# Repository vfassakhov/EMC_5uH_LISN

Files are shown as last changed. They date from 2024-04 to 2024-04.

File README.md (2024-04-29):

# 5µH LISN(Line Impedance Stabilization Network)

Open Source Hardware Dual 5µH DC LISN with 10dB Attenuator and Transient Limiter for Spectrum Analyzer EMC work.

A LISN is a [Line Impedance Stabilization Network](https://en.wikipedia.org/wiki/Line_Impedance_Stabilization_Network) used in conducted emissions testing.

The AIM of this Dual LISN is to be used for EMC pre-testing with frequency range 30kHz(or lower) to 110MHz(or up to 150MHz or more).

Fork from the [original project](https://github.com/bvernoux/EMC_5uH_LISN), the main changes are made the following:

* Convert project to [KiCad 8.0](https://www.kicad.org) version
* Added [KiBot](https://github.com/INTI-CMNB/KiBot) configuration, for automated generation of the documentation
* Improvement in this design: 
  * Replace Keystone 575-8 by screwed type Chinese alternative
  * Inductors are replaced by more affordable (need to make some tests)
  * BOM changes for cheaper Chinese alternatives
  * Another case (Gainta) is chosen

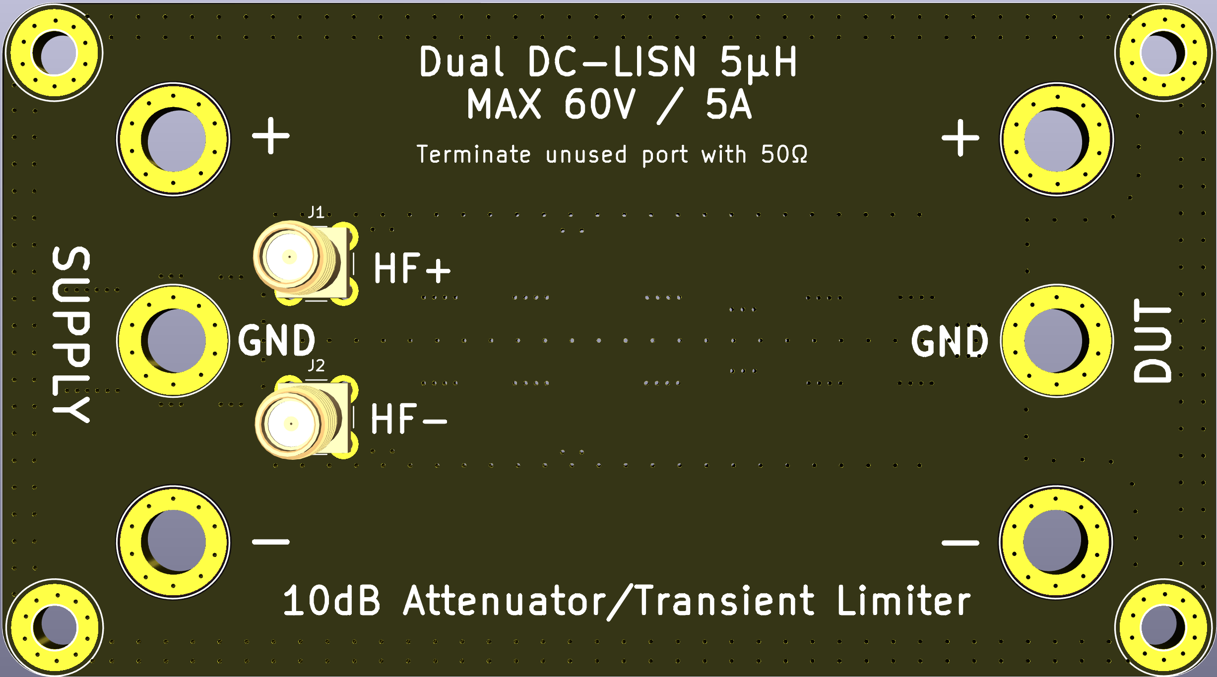
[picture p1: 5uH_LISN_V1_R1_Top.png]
picture of 5uH_LISN_V1_R0_Top

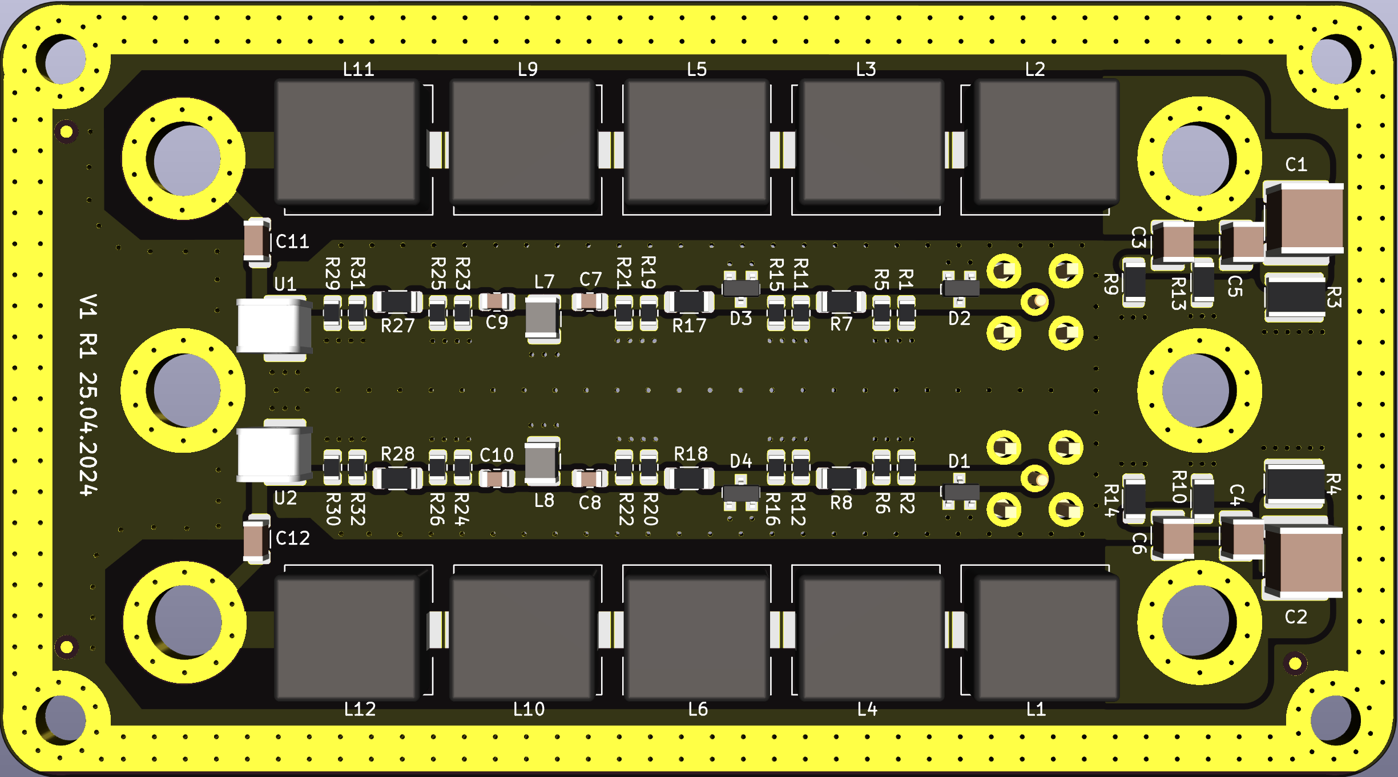
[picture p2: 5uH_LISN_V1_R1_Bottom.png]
picture of 5uH_LISN_V1_R0_Bottom


This work is heavily based on work from others mainly **Jay_Diddy_B** & **Noy** from EEVBLOG forum.

See all links related to the original Dual 5µH LISN:
* https://www.eevblog.com/forum/projects/5uh-lisn-for-spectrum-analyzer-emcemi-work/75/
* https://www.eevblog.com/forum/projects/5uh-lisn-for-spectrum-analyzer-emcemi-work/msg3420102/#msg3420102

Video related to EMC Conducted Emissions / LISN:
* Rohde Schwarz video Understanding LISNs: 
  * This video explains the design and function of a LISN (line impedance stabilization network) and how LISNs are used in conducted EMC testing.
  * https://www.youtube.com/watch?v=QPJzp66Yvzs
* EMC Conducted Emissions: How to connect and set up a LISN:
  * In this video Dr. Ali Shirsavar shows how you can connect and set up a LISN ready for pre-compliance testing of EMC conducted emissions.
  * https://www.youtube.com/watch?v=28oDdL9RnWM

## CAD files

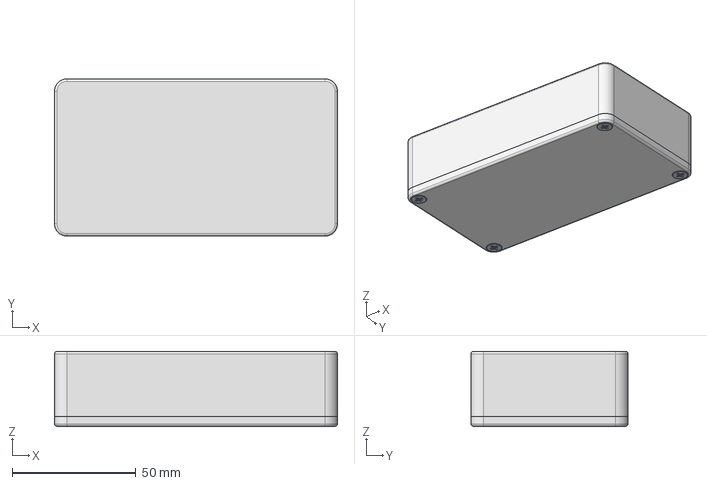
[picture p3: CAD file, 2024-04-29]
3d_step/Gainta_B013_assy.stp
114.5 x 63.6 x 30.4 mm

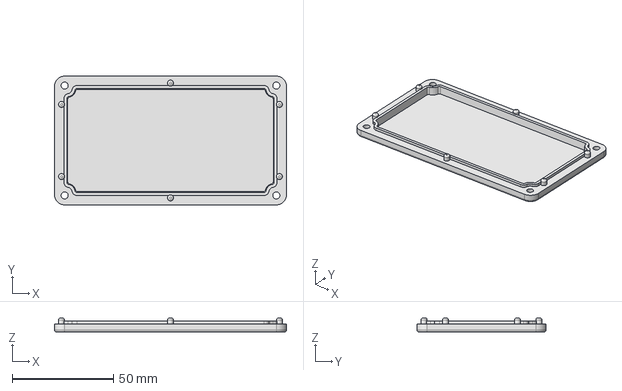
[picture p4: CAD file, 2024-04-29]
3d_step/Gainta_B013_bottom.stp
114.5 x 63.6 x 7.00 mm

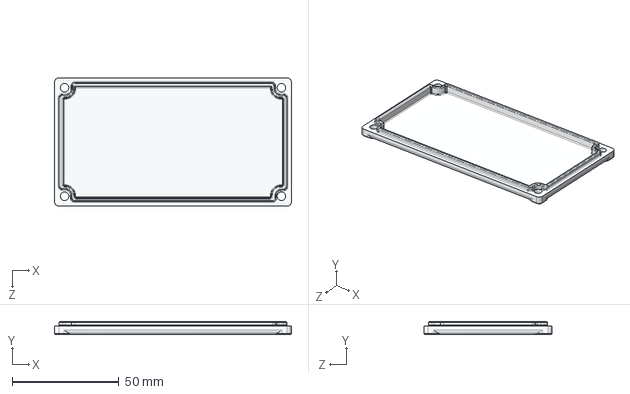
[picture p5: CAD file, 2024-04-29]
3d_step/G0124_BOT.STEP
111.0 x 6.00 x 60.0 mm

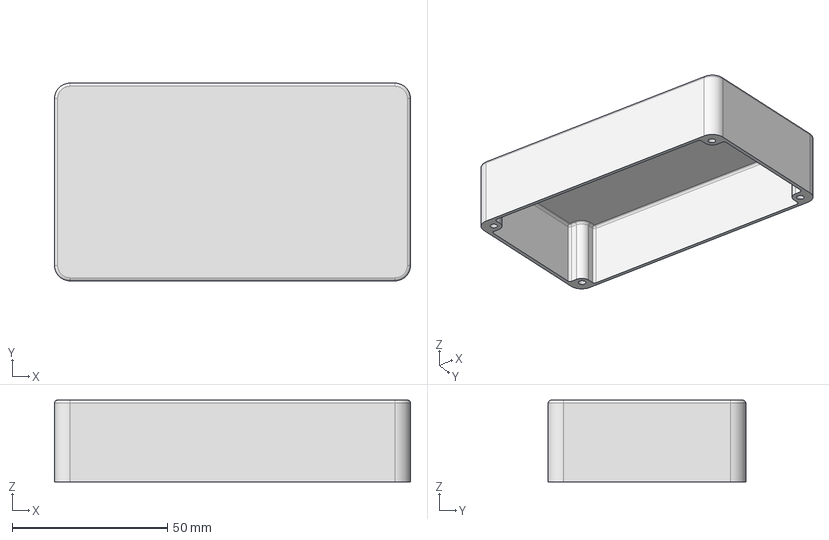
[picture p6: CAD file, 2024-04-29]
3d_step/Gainta_B013_top.stp
114.5 x 63.6 x 26.3 mm

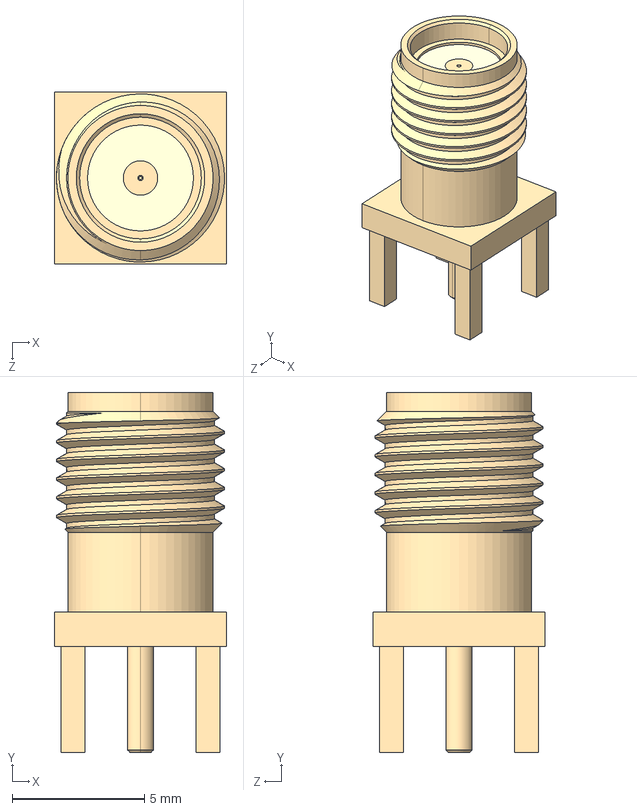
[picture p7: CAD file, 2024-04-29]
3d_step/SMA CONNECTOR--3DModel-STEP-1.STEP
6.50 x 13.6 x 6.50 mm

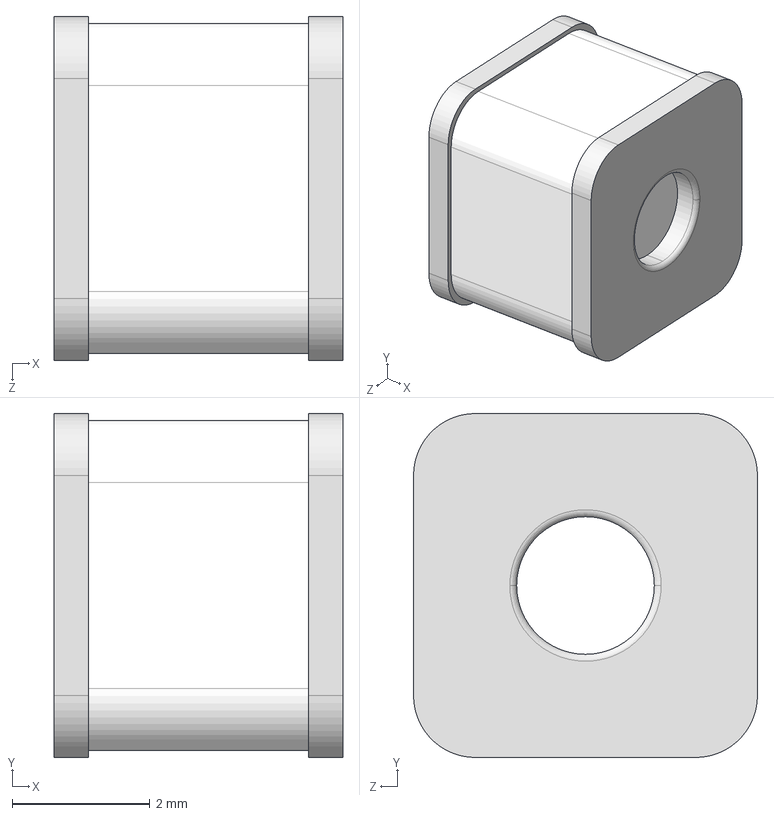
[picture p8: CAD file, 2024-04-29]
3d_step/User Library-SH_Series.STEP
4.20 x 5.00 x 5.00 mm

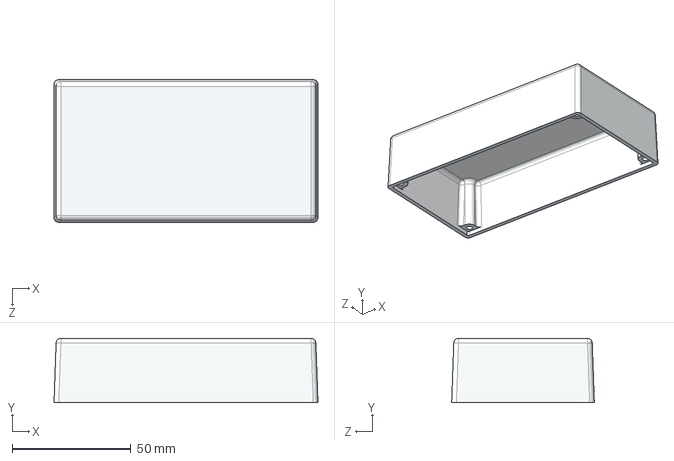
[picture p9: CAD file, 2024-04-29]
3d_step/G0124_TOP.STEP
111.0 x 27.0 x 60.0 mm

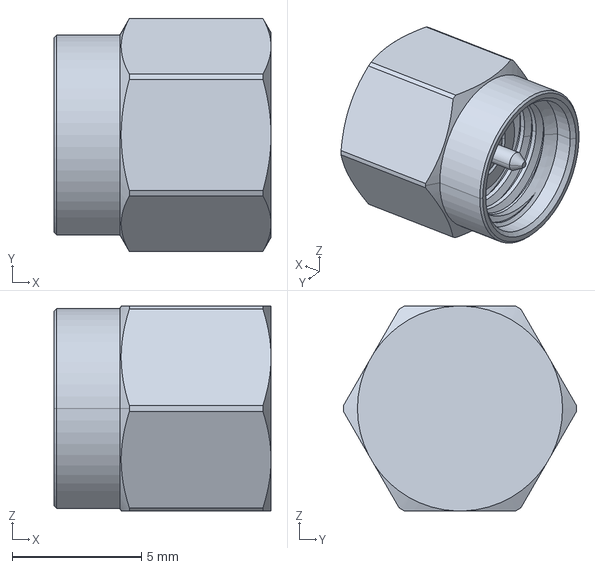
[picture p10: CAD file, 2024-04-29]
3d_step/132360.stp
8.38 x 9.00 x 7.91 mm

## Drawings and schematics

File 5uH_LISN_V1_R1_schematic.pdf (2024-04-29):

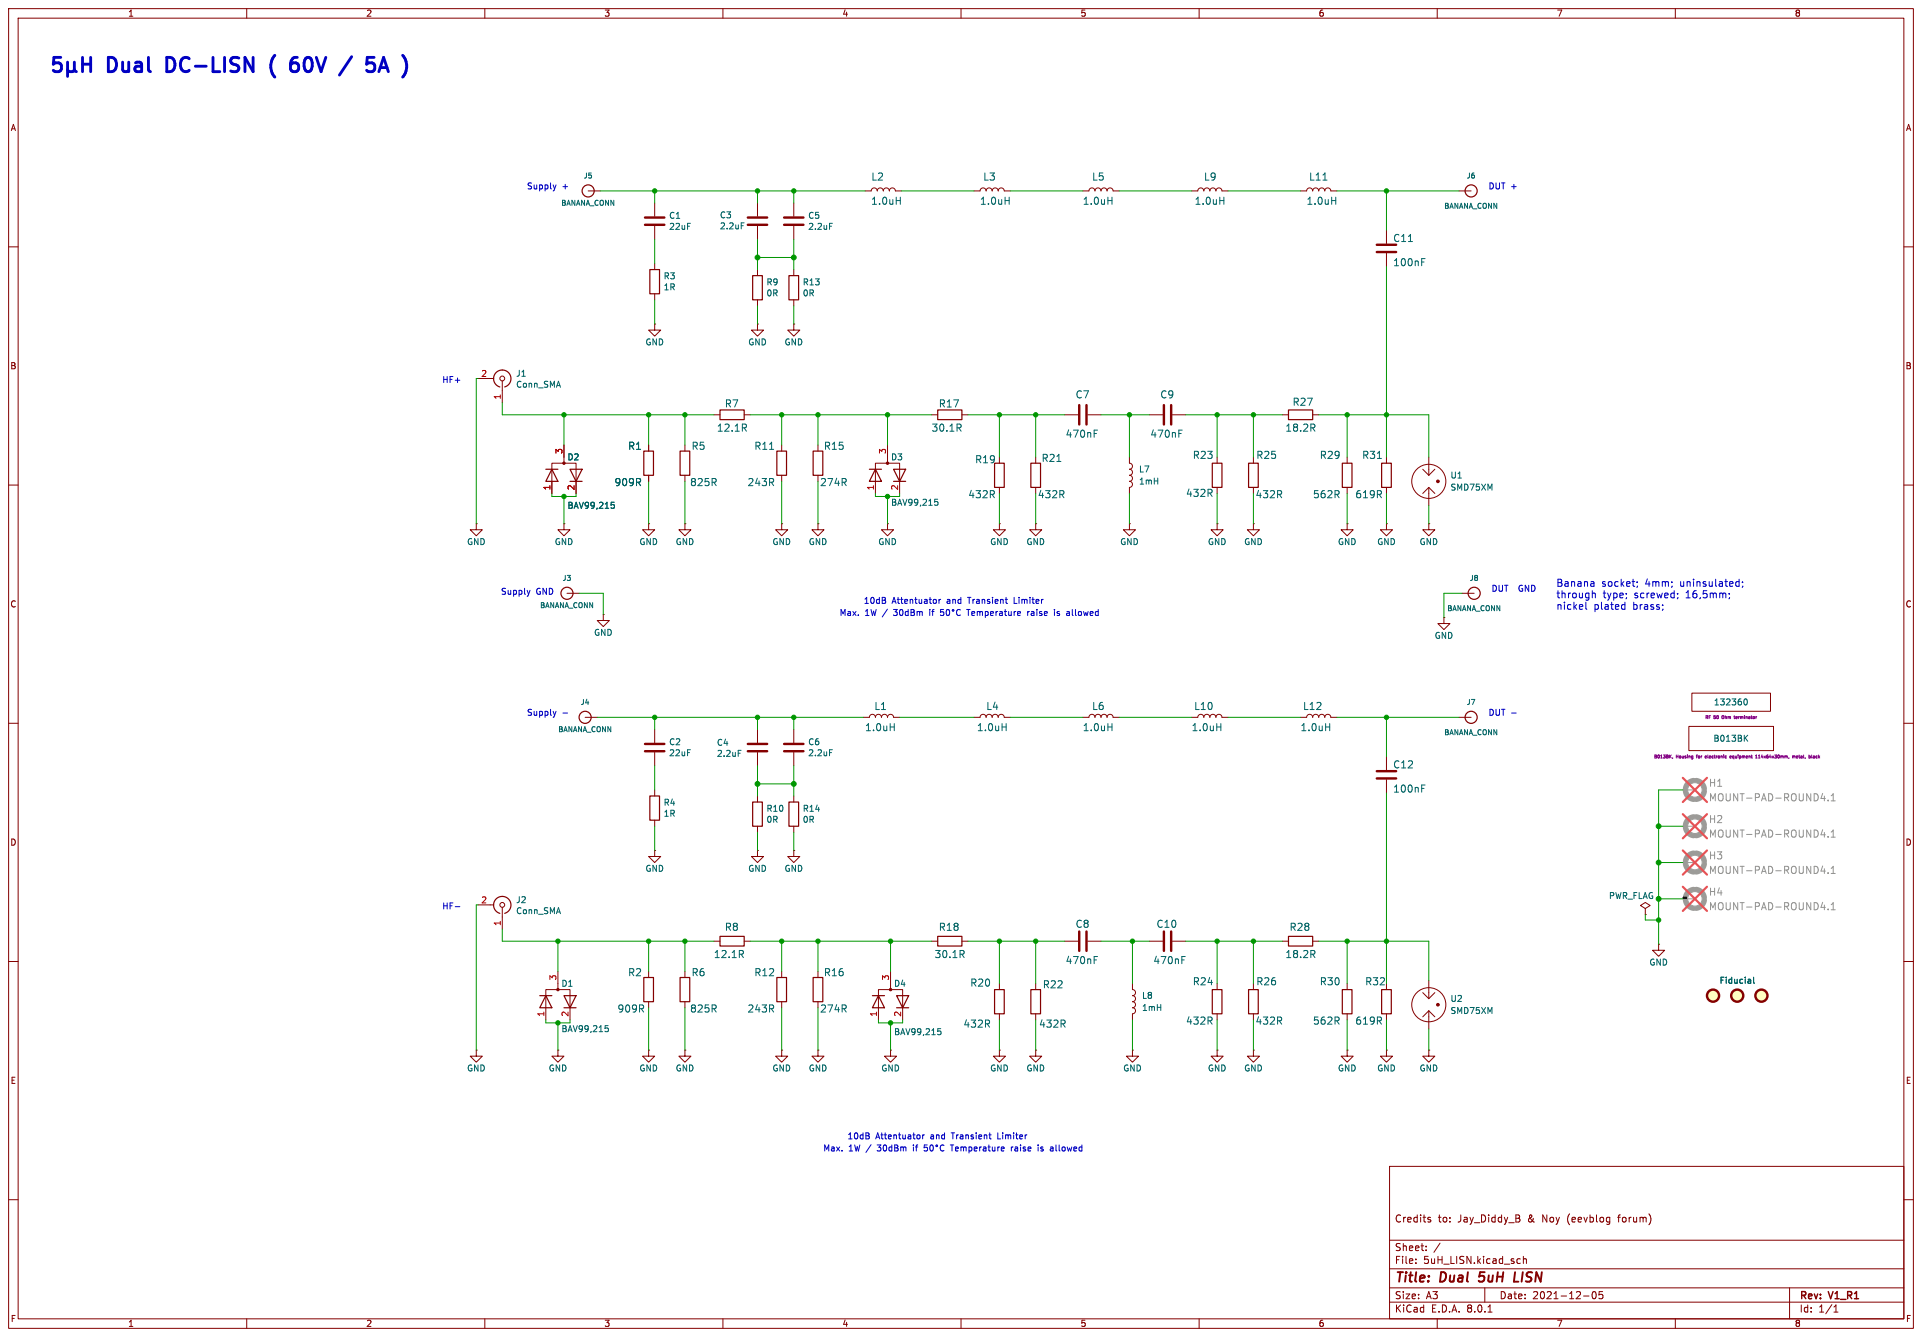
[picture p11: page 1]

RF 50 Ohm terminator H4 MOUNT-PAD-ROUND4.1 H2 MOUNT-PAD-ROUND4.1 H1 MOUNT-PAD-ROUND4.1 H3 MOUNT-PAD-ROUND4.1 B013BK

Id: 1/1 Title: Dual 5uH LISN

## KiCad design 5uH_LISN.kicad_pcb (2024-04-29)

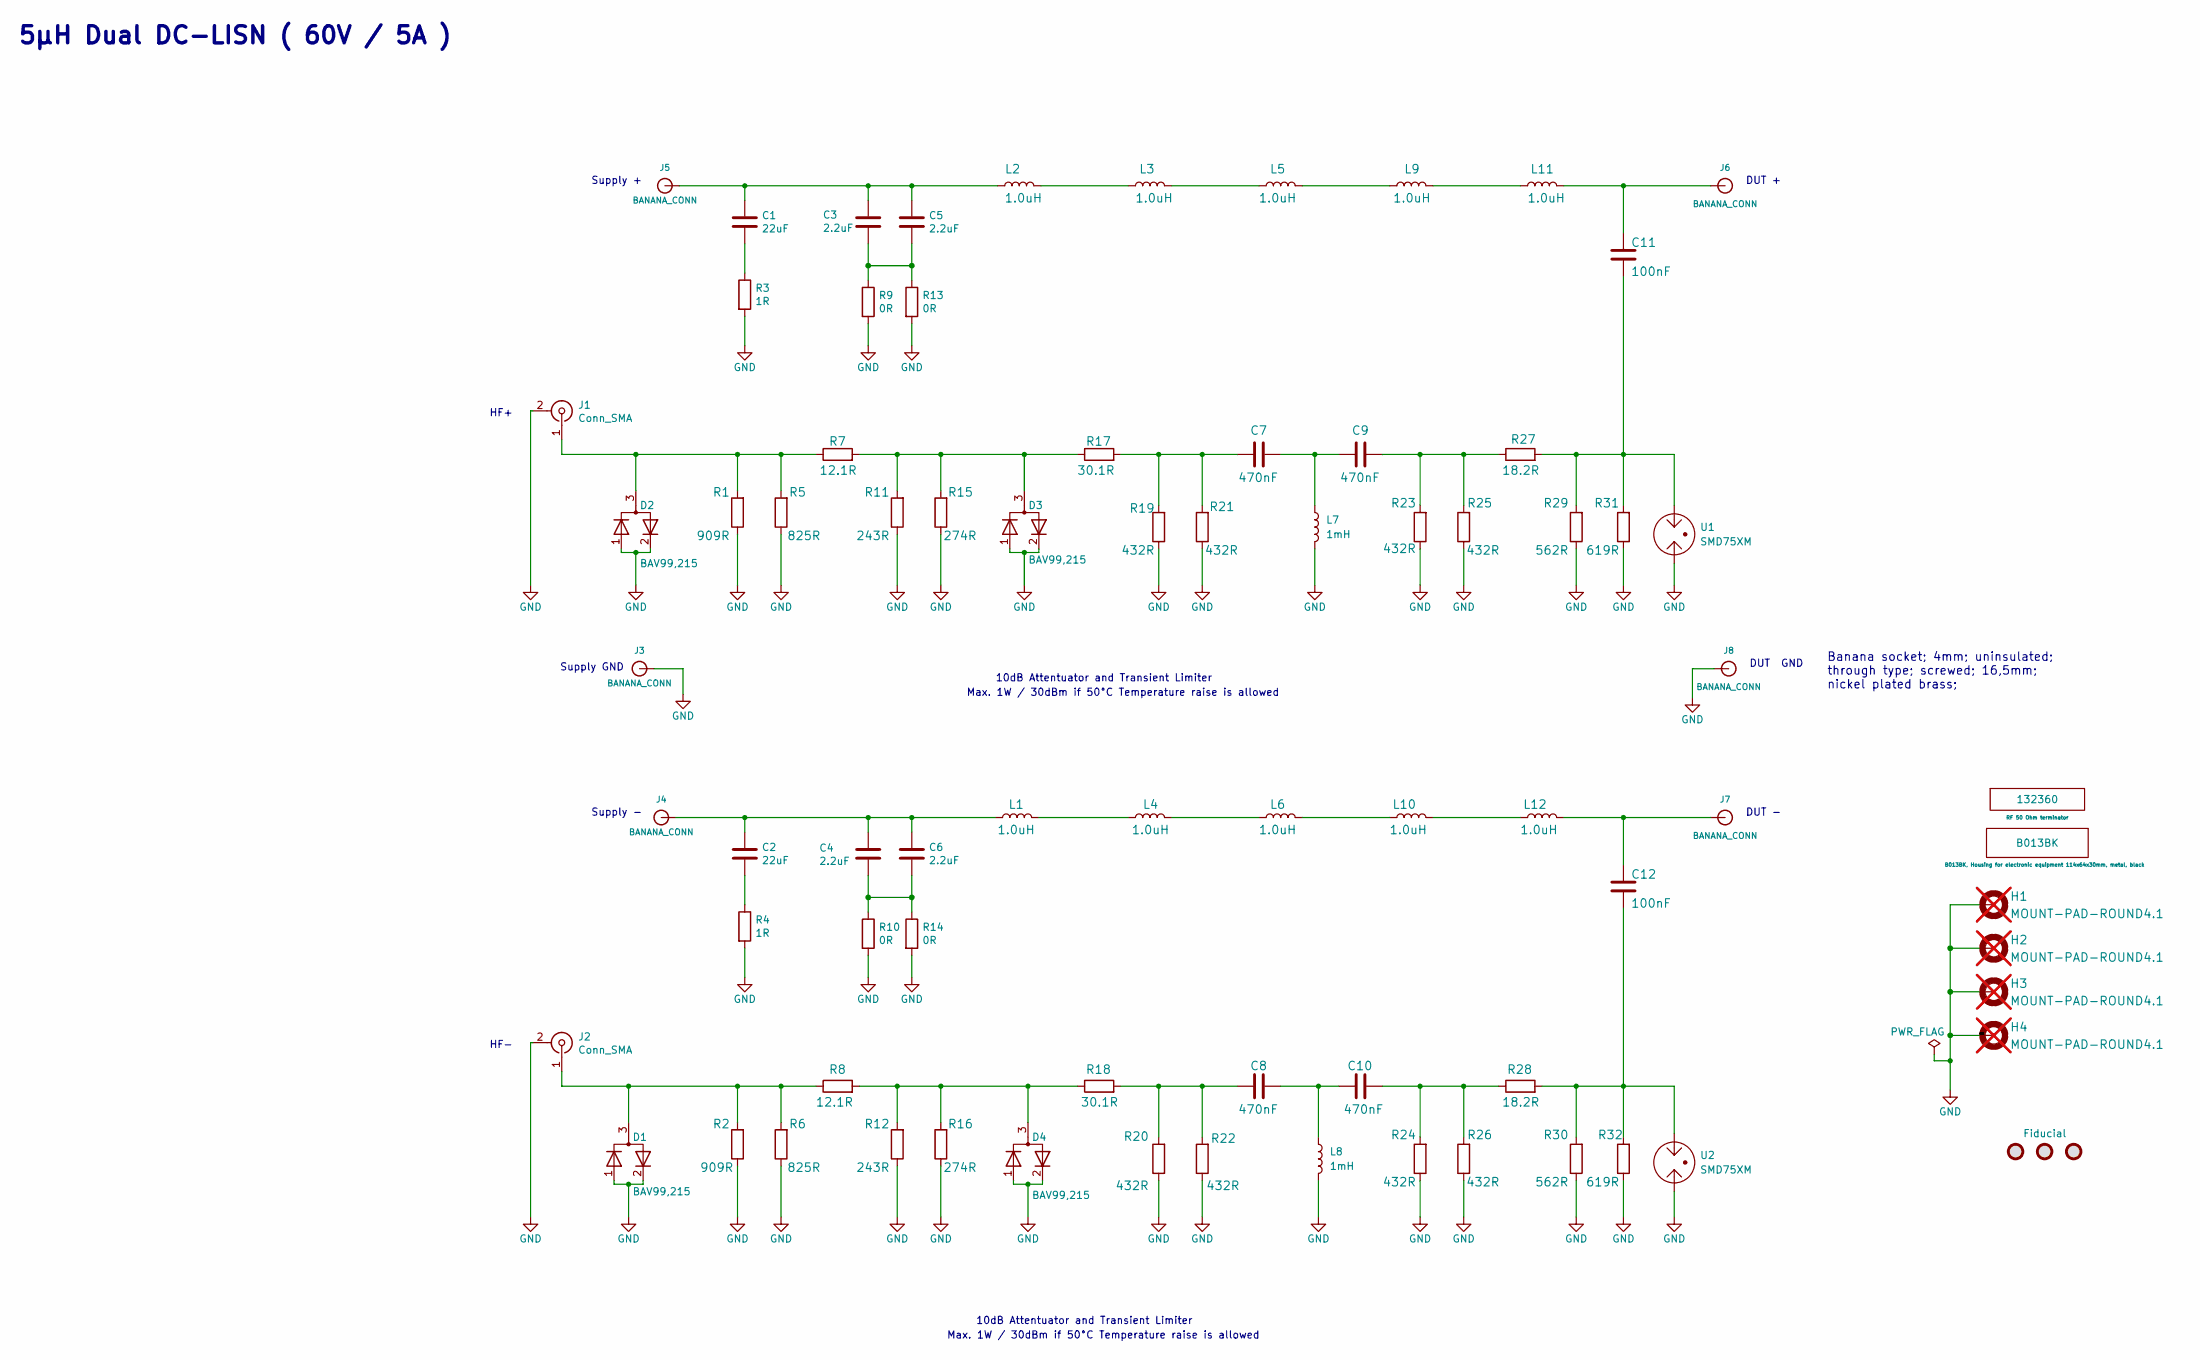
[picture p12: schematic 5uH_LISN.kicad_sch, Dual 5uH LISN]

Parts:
C1, C2: 22uF; C_2220_5650Metric; Part number KRM55WR72A226MH01L
C3, C4, C5, C6: 2.2uF; C_1210_3225Metric; Part number CC1210KKX7R0BB225
C7, C8, C9, C10: 470nF; C_0805_2012Metric; Part number CC0805KKX7R0BB474
C11, C12: 100nF; C_1206_3216Metric; Part number CC1206KKX7RYBB104
CASE1: B013BK; Part number B013BK
D1, D2, D3, D4: BAV99,215; SOT23-DIODEDUAL; Part number BAV99,215
FID1, FID2, FID3: Fiducial; Fiducial_1mm_Mask2mm
H1, H2, H3, H4: MOUNT-PAD-ROUND4.1; 4,1-PAD; not fitted
J1, J2: Conn_SMA; SMB_Jack_Vertical; Part number KLS1-SMA001
J3, J4, J5, J6, J7, J8: BANANA_CONN; 6,1-PAD; Part number 28.230
L1, L2, L3, L4, L5, L6, L9, L10, L11, L12: 1.0uH; SMS1040; Part number SMS1040-1R0MT
L7, L8: 1mH; L_1210_3225Metric; Part number NLFV32T-102K-EF
R1, R2: 909R; R_0805_2012Metric; Part number PTFR0805B909RP9
R3, R4: 1R; R_1218_3246Metric; Part number RC1218FK-071RL
R5, R6: 825R; R_0805_2012Metric; Part number RT0805BRD07825RL
R7, R8: 12.1R; R_1206_3216Metric; Part number RT1206BRD0712R1L
R9, R10, R13, R14: 0R; R_1206_3216Metric; Part number RC1206JR-7W0RL
R11, R12: 243R; R_0805_2012Metric; Part number RT0805BRD07243RL
R15, R16: 274R; R_0805_2012Metric; Part number RT0805BRD07274RL
R17, R18: 30.1R; R_1206_3216Metric; Part number AR06DTDV30R1
R19, R20, R21, R22, R23, R24, R25, R26: 432R; R_0805_2012Metric; Part number RT0805BRD07432RL
R27, R28: 18.2R; R_1206_3216Metric; Part number RT1206BRD0718R2L
R29, R30: 562R; R_0805_2012Metric; Part number RT0805BRD07562RL
R31, R32: 619R; R_0805_2012Metric; Part number RT0805BRE07619RL
RF1: 132360; RF_CAP; Part number 132360
U1, U2: SMD75XM; Fuse_1812_4532Metric; Part number SMD75XM

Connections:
GND: D1.1 (K), D1.2 (K), D2.1 (K), D2.2 (K), D3.1 (K), D3.2 (K), D4.1 (K), D4.2 (K), H1.B4,1 (MOUNT), H2.B4,1 (MOUNT), H3.B4,1 (MOUNT), H4.B4,1 (MOUNT), J1.2 (Ext), J2.2 (Ext), J3.1, J8.1, L7.2, L8.2, R1.1, R2.1, R3.2, R4.2, R5.1, R6.1, R9.2, R10.2, R11.1, R12.1, R13.2, R14.2, R15.1, R16.1, R19.1, R20.1, R21.1, R22.1, R23.1, R24.1, R25.1, R26.1, R29.1, R30.1, R31.1, R32.1, U1.1, U2.1
unnamed: C1.2, R3.1
unnamed: C2.2, R4.1
unnamed: C3.2, C5.2, R9.1, R13.1
unnamed: C4.2, C6.2, R10.1, R14.1
unnamed: C7.1, R17.2, R19.2, R21.2
unnamed: C7.2, C9.1, L7.1
unnamed: C8.1, R18.2, R20.2, R22.2
unnamed: C9.2, R23.2, R25.2, R27.1
unnamed: C8.2, C10.1, L8.1
unnamed: C10.2, R24.2, R26.2, R28.1
unnamed: C11.2, R27.2, R29.2, R31.2, U1.2
unnamed: C12.2, R28.2, R30.2, R32.2, U2.2
unnamed: D1.3 (A), J2.1 (In), R2.2, R6.2, R8.1
unnamed: D2.3 (A), J1.1 (In), R1.2, R5.2, R7.1
unnamed: D3.3 (A), R7.2, R11.2, R15.2, R17.1
unnamed: D4.3 (A), R8.2, R12.2, R16.2, R18.1
unnamed: C2.1, C4.1, C6.1, J4.1, L1.1
unnamed: C1.1, C3.1, C5.1, J5.1, L2.1
unnamed: C11.1, J6.1, L11.2
unnamed: C12.1, J7.1, L12.2
unnamed: L1.2, L4.1
unnamed: L2.2, L3.1
unnamed: L3.2, L5.1
unnamed: L4.2, L6.1
unnamed: L5.2, L9.1
unnamed: L6.2, L10.1
unnamed: L10.2, L12.1
unnamed: L9.2, L11.1

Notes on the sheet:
10dB Attentuator and Transient Limiter
Supply -
Max. 1W / 30dBm if 50°C Temperature raise is allowed
5µH Dual DC-LISN ( 60V / 5A )
DUT +
Supply +
DUT GND
Banana socket; 4mm; uninsulated; through type; screwed; 16,5mm; nickel plated brass;
Supply GND
HF-
HF+
DUT -

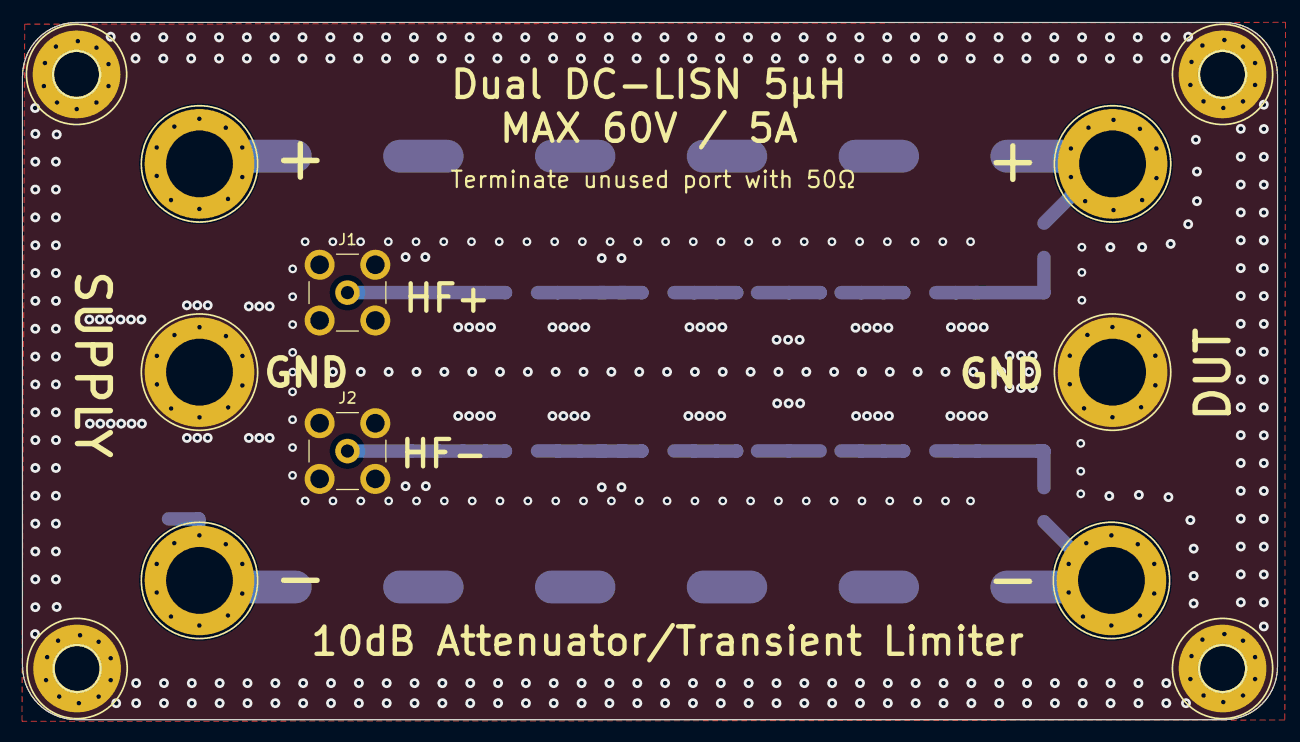
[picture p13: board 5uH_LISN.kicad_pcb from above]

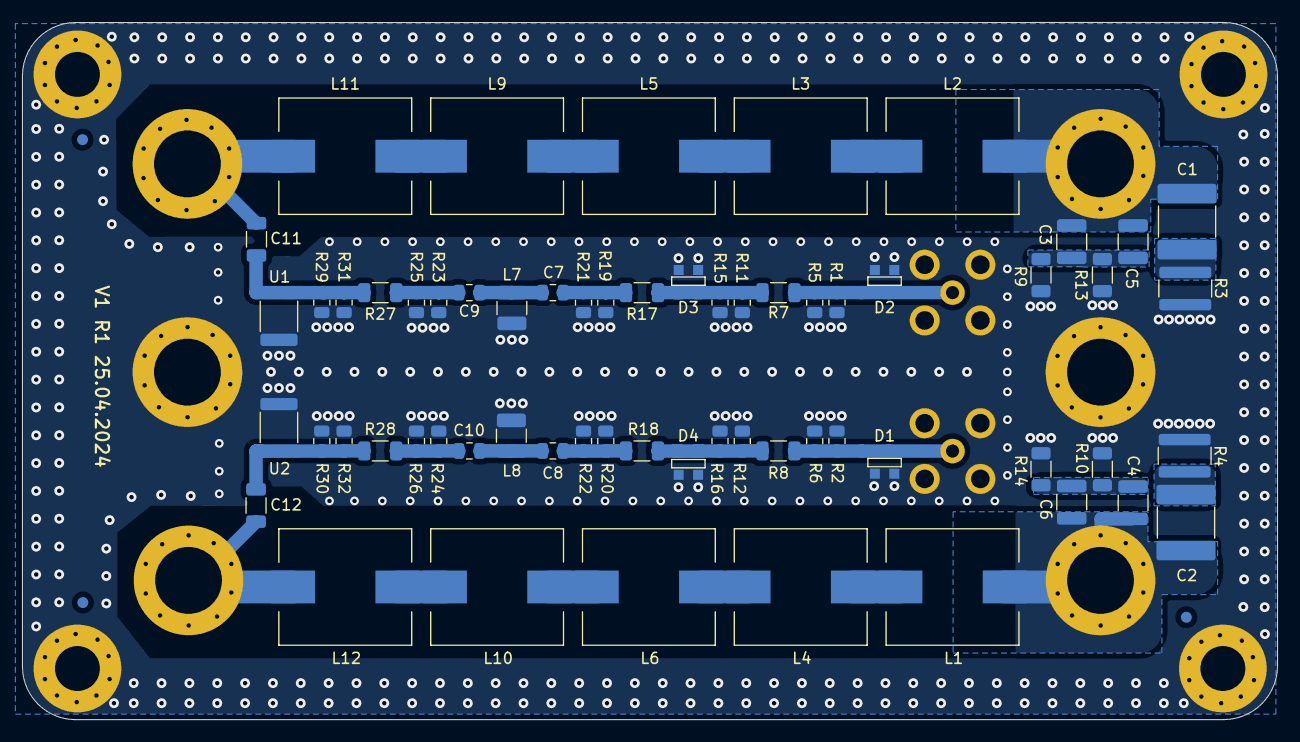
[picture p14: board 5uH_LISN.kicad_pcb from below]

Board: 2 copper layers, 114.5 x 63.6 mm, 79 parts (65 on the bottom side), 29 nets.
